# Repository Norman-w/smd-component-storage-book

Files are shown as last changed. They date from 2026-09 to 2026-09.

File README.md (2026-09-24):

# 0603 编带收纳活页页

当前版本是 ISO A5 纵向页面，外廓 `148 × 210 mm`，默认 18 条平行滑道。页面左侧带常见 A5 六孔圆孔列，标签卡槽底面保持完整，卡槽由底板上方增高的 T 形墙体形成。

当前源模型为 v22：标签纸仍为 `25 × 9 mm`，从右向左插入；底板不再挖浅槽，标签上下两侧与编带槽共用“下宽上窄”的 T 形卡口。入口压边的外侧边保持直线，只让朝标签内侧的边收斜，俯视轮廓为“个”字形而不是两边都收窄的 Y 形。编带内宽约 `8.6 mm`，双侧 T 形压边每侧覆盖约 `1.3 mm`，顶部有效开口约 `6.0 mm`；相邻滑道用约 `0.8 mm` 共用薄墙直接相接，页面保持 18 条滑道。

当前工作树保留连续外圈围墙：围墙高约 `3.45 mm`、平面内墙厚 `2.0 mm`，从页面最外缘向内形成加强边，既帮助装订后保持页面平整，也作为每条编带滑道的右端止挡。左侧装订区域从页面边缘到孔列内侧加强脊全部满铺到同一高度，孔洞贯穿高台，以提升装订孔抗撕裂能力。新版导出文件使用 `_v22_z_wall_t_slot` 文件名。

## 使用与商业授权

本作品默认仅供个人学习、测试、收藏和非商业打印使用。未经作者书面许可，禁止将原模型或任何基于本模型的改造、缩放、修补、重混或衍生版本用于商业用途，包括但不限于：销售打印件、按需打印或代打服务、批量生产、产品配套或赠品、手板/复模、定制服务、商业展示，以及上传或销售商业衍生模型。

如需商业使用，请在使用前联系作者（MakerWorld / GitHub：`@NormanWang`）取得书面授权，并另行约定授权费、单件费用、销售额分成或利润分成。未获授权的商业使用，作者保留要求停止使用、下架、追究侵权责任及索取相应授权费用或损害赔偿的权利。完整条款见 [`LICENSE.md`](LICENSE.md)。

## 设计假设

- FDM / PETG / 0.4 mm 喷嘴；底板为 `0.6 mm` 极薄版本，约对应 0.2 mm 层高的 3 层实体，不是单层空壳。
- T 形压边每侧内收 `1.3 mm`，压边材料厚 `1.0 mm`、上压高度 `0.9 mm`；相邻 `11.0 mm` 行距滑道共用约 `0.8 mm` 薄隔档，目标为普通 PETG、0.4 mm 喷嘴、无支撑打印。
- 页面平放打印，设计目标是不使用支撑。
- 页面最外圈增加连续圆角围墙，平面内墙厚 `2.0 mm`、高度与 T 形滑道最高点一致；编带滑道直接延伸到外墙内侧，不再额外设置右端挡块。
- 载带默认按 8 mm 压纹塑料带估算：宽度 8 mm、最大凸包高度 1.8 mm。
- 双侧 T 形限位是正式页面默认结构；单侧 7 形只用于对照测试片。
- 装订孔默认采用 A5 六孔制式，孔径 `5.5 mm`，孔中心距左边 `6.5 mm`，纵向位置为 `32 / 51 / 70 / 140 / 159 / 178 mm`；参数可在 `src/params.scad` 调整。
- 标签槽右边缘与对应滑道入口约留 `1 mm`，纸片标签从右向左插入，左端由装订孔旁加强高台止挡，标签槽挪出的空间让给编带滑道。
- 标签纸仍按 `25 × 9 mm` 使用；标签卡槽不削薄 `0.6 mm` 底板，支脚从底板顶面向上增高，标签下方有效容纳高度约 `0.7 mm`。主体上、下压边覆盖量约 `2.8 mm`，每格右侧入口前 `4.5 mm` 采用上下镜像的浅压边；外侧边保持直线，只收窄朝标签内侧的边。相邻标签共用水平隔档，主体标签窗口仍保留约 `9.8 mm` 高度。
- 滑道入口改为短装入豁口：横挡后的实际窗口约 `6 mm`，左端横挡高度降为 `1.8 mm`，T 形压边从其后立即开始，兼顾推进手感和防掉出。
- 编带槽内宽约 `8.6 mm`，顶部有效开口约 `6.0 mm`，优先加强编带防脱；槽间不留空白，直接共用约 `0.8 mm` 薄隔档，共容纳 18 条滑道。
- 所有载带包络和配合间隙集中在 `src/params.scad`。

## 导出

本机 OpenSCAD 应用程序路径：

```sh
OPENSCAD=/Applications/OpenSCAD.app/Contents/MacOS/OpenSCAD

"$OPENSCAD" --export-format binstl \
  -o output/3d-print/0603_tape_page_v22_z_wall_t_slot.stl \
  src/0603_tape_page.scad

"$OPENSCAD" --export-format binstl \
  -o output/3d-print/0603_fit_coupon_dual_t_v22_z_wall_t_slot.stl \
  -D 'model_selector="fit_dual_t"' src/0603_tape_page.scad

"$OPENSCAD" --export-format binstl \
  -D 'model_selector="fit_single_7"' \
  -o output/3d-print/0603_fit_coupon_single_7_v22_z_wall_t_slot.stl \
  src/0603_tape_page.scad
```

底板完整 + 标签上凸 T 形墙 + 单侧内边斜入口 + 装订边满铺加强版 v22 输出：

```text
output/3d-print/0603_tape_page_v22_z_wall_t_slot.stl
output/3d-print/0603_fit_coupon_dual_t_v22_z_wall_t_slot.stl
```

## 16 mm 编带变体

16 mm 版采用紧凑共墙布局，修正了旧版每格之间出现额外空白隔道的问题：

- 编带有效内宽 `16 mm`
- A5 页面 `11` 条滑道
- 行距 `17.2 mm = 16.0 + 0.2 + 0.8 + 0.2`
- `0.8 mm` 是相邻轨道共用的一条薄墙；不再在两条轨道之间额外插入第二条隔墙
- 两侧各保留 `0.2 mm` 装入余量
- 编带凸包高度仍按当前版本的 `1.8 mm`；若实物高度不同，只需调整 `tape_height`

导出 16 mm 整页和双侧 T 测试片：

```sh
"$OPENSCAD" --export-format binstl \
  -D 'tape_width=16' -D 'tape_side_clearance=0.2' \
  -D 'lane_count=11' -D 'lane_pitch=17.2' -D 'label_height=12' \
  -o output/3d-print/0603_tape_page_16mm_label12_tight_v1.stl \
  src/0603_tape_page.scad

"$OPENSCAD" --export-format binstl \
  -D 'model_selector="fit_dual_t"' \
  -D 'tape_width=16' -D 'tape_side_clearance=0.2' \
  -D 'lane_count=11' -D 'lane_pitch=17.2' -D 'label_height=12' \
  -o output/3d-print/0603_fit_coupon_dual_t_16mm_label12_tight_v1.stl \
  src/0603_tape_page.scad

"$OPENSCAD" --export-format binstl \
  -D 'model_selector="fit_single_7"' \
  -D 'tape_width=16' -D 'tape_side_clearance=0.2' \
  -D 'lane_count=11' -D 'lane_pitch=17.2' -D 'label_height=12' \
  -o output/3d-print/0603_fit_coupon_single_7_16mm_label12_tight_v1.stl \
  src/0603_tape_page.scad
```

对应的紧凑 16 mm STL 位于 `output/3d-print/`，整页包围盒为 `148 × 210 × 3.45 mm`，并通过封闭流形检查。

### 16 mm 编带 + 12 mm 标签变体

针对 16 mm 编带，平台发布版使用标签横向宽度 `12 mm`；标签沿插入方向的长度仍为 `25 mm`。这只覆盖 `label_height=12`，并使用紧凑的 `17.2 mm` 行距。

```sh
"$OPENSCAD" --export-format binstl \
  -D 'tape_width=16' -D 'tape_side_clearance=0.2' \
  -D 'lane_count=11' -D 'lane_pitch=17.2' \
  -D 'label_height=12' \
  -o output/3d-print/0603_tape_page_16mm_label12_tight_v1.stl \
  src/0603_tape_page.scad

"$OPENSCAD" --export-format binstl \
  -D 'model_selector="fit_dual_t"' \
  -D 'tape_width=16' -D 'tape_side_clearance=0.2' \
  -D 'lane_count=11' -D 'lane_pitch=17.2' \
  -D 'label_height=12' \
  -o output/3d-print/0603_fit_coupon_dual_t_16mm_label12_tight_v1.stl \
  src/0603_tape_page.scad
```

整页 12 mm 标签变体同样为 `148 × 210 × 3.45 mm`，并已通过封闭流形检查。

## 平台发布的六种编带宽度

平台草稿准备提供六份独立的整页 STL，避免用户误选宽度：

| 编带有效内宽 | 标签卡 | 滑道数 / 行距 | 平台文件 |
|---:|---:|---:|---|
| 8 mm | 25 × 9 mm | 18 / 11.0 mm | `output/3d-print/0603_tape_page_8mm_label9_v1.stl` |
| 12 mm | 25 × 12 mm | 15 / 13.2 mm | `output/3d-print/0603_tape_page_12mm_label12_v1.stl` |
| 16 mm | 25 × 12 mm | 11 / 17.2 mm | `output/3d-print/0603_tape_page_16mm_label12_tight_v1.stl` |
| 24 mm | 25 × 12 mm | 8 / 25.2 mm | `output/3d-print/0603_tape_page_24mm_label12_v1.stl` |
| 32 mm | 25 × 12 mm | 6 / 33.2 mm | `output/3d-print/0603_tape_page_32mm_label12_v1.stl` |
| 44 mm | 25 × 12 mm | 4 / 45.2 mm | `output/3d-print/0603_tape_page_44mm_label12_v1.stl` |

8 mm 和 12 mm 沿用已经确认/打印验证的页面；16 / 24 / 32 / 44 mm 使用紧凑共墙布局。六种版本都是 A5、六孔、完整底板、连续外圈围墙和双侧 T 形编带限位。

24 / 32 mm 版本暂按 `3.0 mm` 载带/料槽高度包络建模；44 mm 版本暂按 `3.6 mm` 高度包络建模，作为 ESP32-WROOM 类模组载带的初始版本。载带宽度、料槽深度和元件凸包高度仍需以实物测量为准，正式装满整卷前应先打印对应测试片。

## B5 横向长轨变体

为在左侧继续装订/开合的前提下增加左右方向的存储长度，另提供 `250 × 176 mm` 的 ISO B5 横向页面。左侧保留六孔，孔径 `5.5 mm`，孔距 `19 mm`，孔中心位置为 `15 / 34 / 53 / 123 / 142 / 161 mm`。250 mm 长边在 X1C 的 256 mm 打印轴内约剩 3 mm 单边余量，打印时应精确放置并关闭 brim。

| 编带有效内宽 | 滑道数 / 行距 | 页面高度 | 平台文件 |
|---:|---:|---:|---|
| 8 mm | 15 / 11.0 mm | 3.45 mm | `output/3d-print/0603_tape_page_b5_8mm_label9_v1.stl` |
| 12 mm | 12 / 13.2 mm | 3.45 mm | `output/3d-print/0603_tape_page_b5_12mm_label12_v1.stl` |
| 16 mm | 9 / 17.2 mm | 3.45 mm | `output/3d-print/0603_tape_page_b5_16mm_label12_tight_v1.stl` |
| 24 mm | 6 / 25.2 mm | 4.65 mm | `output/3d-print/0603_tape_page_b5_24mm_label12_v1.stl` |
| 32 mm | 5 / 33.2 mm | 4.65 mm | `output/3d-print/0603_tape_page_b5_32mm_label12_v1.stl` |
| 44 mm | 3 / 45.2 mm | 5.25 mm | `output/3d-print/0603_tape_page_b5_44mm_label12_v1.stl` |

B5 版的编带插入方向有效长度约 `208 mm`，约为当前 A5 版 `106 mm` 的两倍；相邻滑道仍直接共用约 `0.8 mm` 薄隔墙。

## 当前打印验证版：12 mm 编带 + 12 mm 标签

本次打印采用独立的 A5 版本：编带净宽按 `12 mm`，标签卡按 `25 × 12 mm`，页面共 `15` 条滑道，滑道中心距为 `13.2 mm`。中心距按 `12 mm` 有效空间、约 `0.8 mm` 共用隔墙和两侧合计 `0.4 mm` 装入余量计算；相邻滑道直接共墙，不再留无效空隙。

该版本仍保留 A5 六孔装订、完整 `0.6 mm` 底板、上凸 T 形卡槽、连续 `2.0 mm` 外圈加强墙和无支撑平放打印目标。整页包围盒为 `148 × 210 × 3.45 mm`，页面与双 T 测试片均通过封闭流形检查。X1C 直接打印工程使用普通 PETG、纹理 PEI 板和 `0.20 mm` 层高。

对应文件：

```text
output/3d-print/0603_tape_page_12mm_label12_v1.stl
output/3d-print/0603_tape_page_12mm_label12_x1c_safe_v1.stl
output/3d-print/0603_tape_page_12mm_label12_x1c_petg_v1.3mf
output/3d-print/0603_fit_coupon_dual_t_12mm_label12_v1.stl
```

`_x1c_safe_v1.stl` 已将页面放到 X1C 床面安全区域；`.3mf` 是已切片的直接打印工程。当前版本先保留为独立输出，不改变 `src/params.scad` 中默认的 8 mm 编带参数。

### X1C 直接打印工程

为避免 Bambu Studio 导入 STL 后把页面放进左下角校准避让区，另提供同一几何体的 X1C 安全坐标包装版：页面位于 `x=54..202 mm`、`y=23..233 mm`，几何包围盒仍为 `148 × 210 × 3.45 mm`。

```text
src/0603_tape_page_16mm_label12_tight_x1c_safe.scad
output/3d-print/0603_tape_page_16mm_label12_tight_v1.stl
```

16 mm 紧凑版目前先提供已验证的 STL 和 X1C 安全坐标包装源文件；三种宽度的统一 3MF 工程待平台版本确认后再生成。打印时使用 Bambu Lab X1 Carbon、0.4 mm 喷嘴、0.20 mm Standard、普通 PETG、纹理 PEI 板；发送到打印机时可在 AMS 中把普通 PETG 映射到第 3 或第 4 槽。

## 打印前检查

先打印测试片，用实际 0603 编带验证插入、竖直防脱、镊子取料和 `25 × 9 mm` 标签插入。确认后再打印整页。PETG 大面积平板建议使用干燥耗材、纹理 PEI，并按切片结果决定是否加小幅 brim。

STL 导出后还需要检查包围盒、流形性、底面连续性和 T 形压边是否能无支撑成形。STL 导出成功本身不等于实际配合已经验证。

## X1C 局域网打印工程

已准备好可直接在 Bambu Studio 打开的切片工程：

```text
output/3d-print/0603_tape_page_v1_x1c_petg_standard.3mf
```

工程使用 Bambu Lab X1 Carbon、0.4 mm 喷嘴、PETG Basic 和纹理 PEI 板，并在工程内明确写入 `256 × 256 × 256 mm` 打印区及左下角 `18 × 28 mm` 校准避让区。当前 v4 页面通过 `src/0603_tape_page_x1c_safe.scad` 以 `54 / 23 mm` 放置，实际页面约为 `148 × 210 × 3.45 mm`，不会占用左下校准区。

质量优先参数：

- 层高 `0.20 mm`，首层 `0.20 mm`；2 圈外墙，底部 3 层，顶部 4 层，填充 `0%`。
- PETG 喷嘴 `255°C`，纹理 PEI 热床首层及其余层 `80°C`。
- 首层 `20 mm/s`，外墙 `45 mm/s`，内墙 `60 mm/s`，顶面 `60 mm/s`。
- 默认/外墙加速度 `500 mm/s²`，首层 `300 mm/s²`，风扇范围 `10–40%`，最大体积流量 `8 mm³/s`。
- 关闭 skirt，外裙边改为 `1 mm`；A5 页面在 X1C 床面上有充足边缘余量，可按首层观察结果决定是否加 brim。

该 `.3mf` 是上一版 B5 工程，不能代表当前 A5 v22 几何；正式打印前应在 Bambu Studio 中导入新的 v22 STL，确认 X1C 当前装的是干燥 PETG、纹理 PEI 板已清洁，并先用双 T 测试片确认实际编带和右侧标签配合。

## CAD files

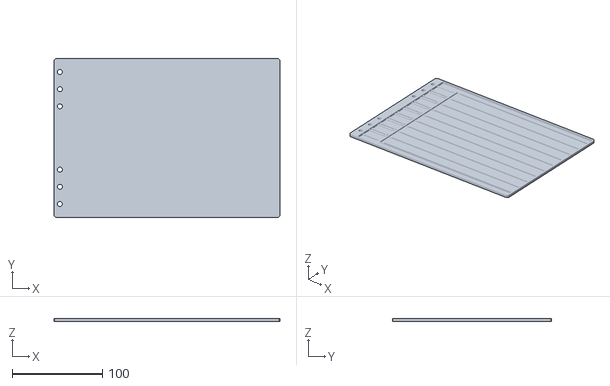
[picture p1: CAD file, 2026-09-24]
output/3d-print/0603_tape_page_b5_16mm_label12_tight_v1.stl
250.0 x 176.0 x 3.45

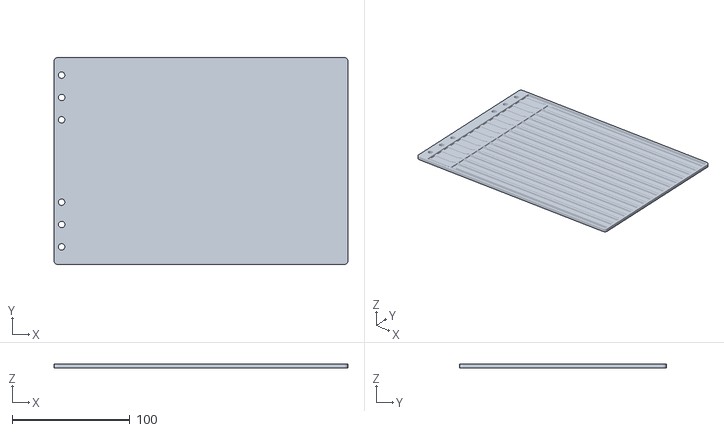
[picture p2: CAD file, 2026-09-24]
output/3d-print/0603_tape_page_b5_8mm_label9_v1.stl
250.0 x 176.0 x 3.45

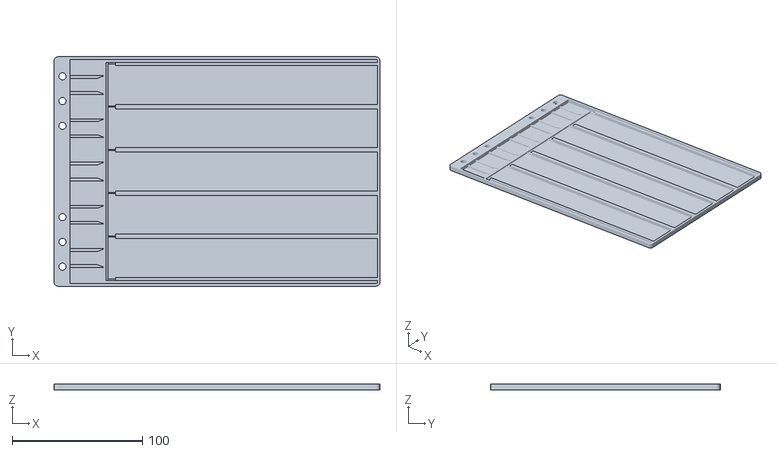
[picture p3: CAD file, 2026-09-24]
output/3d-print/0603_tape_page_b5_32mm_label12_v1.stl
250.0 x 176.0 x 4.65

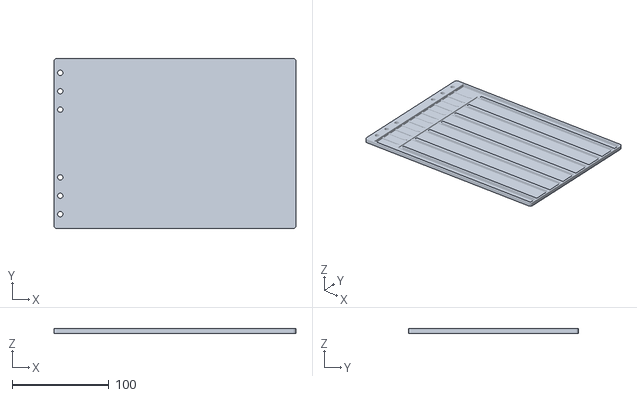
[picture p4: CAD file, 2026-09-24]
output/3d-print/0603_tape_page_b5_24mm_label12_v1.stl
250.0 x 176.0 x 4.65

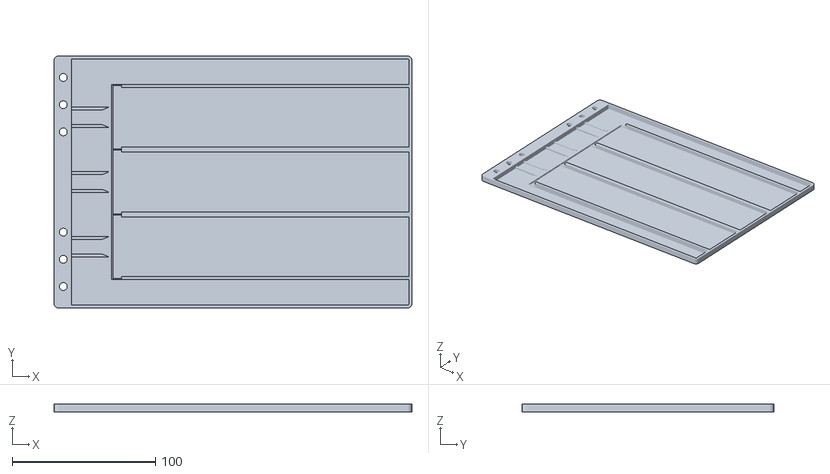
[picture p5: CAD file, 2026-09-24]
output/3d-print/0603_tape_page_b5_44mm_label12_v1.stl
250.0 x 176.0 x 5.25

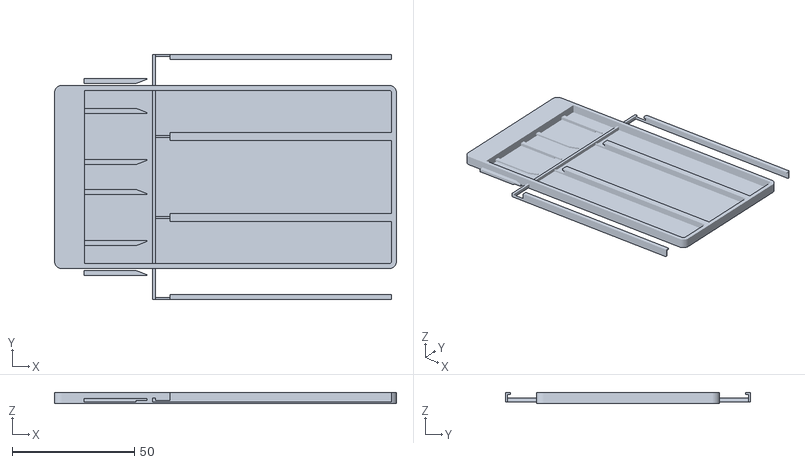
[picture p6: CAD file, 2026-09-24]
output/3d-print/0603_fit_coupon_dual_t_32mm_label12_v1.stl
140.0 x 100.4 x 4.65

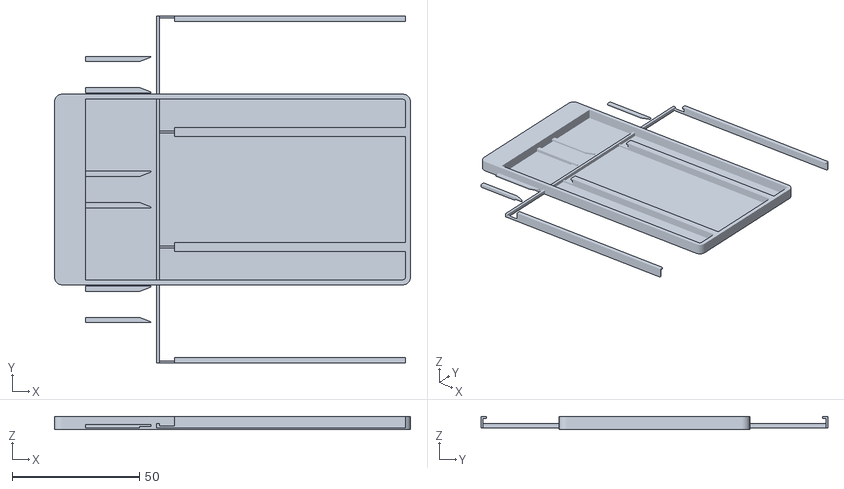
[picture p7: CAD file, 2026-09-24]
output/3d-print/0603_fit_coupon_dual_t_44mm_label12_v1.stl
140.0 x 136.4 x 5.25

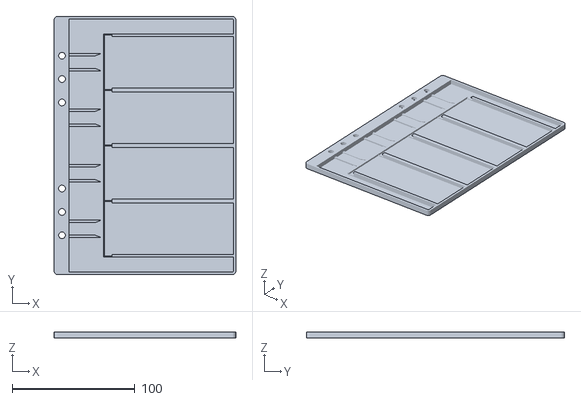
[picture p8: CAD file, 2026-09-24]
output/3d-print/0603_tape_page_44mm_label12_v1.stl
148.0 x 210.0 x 5.25

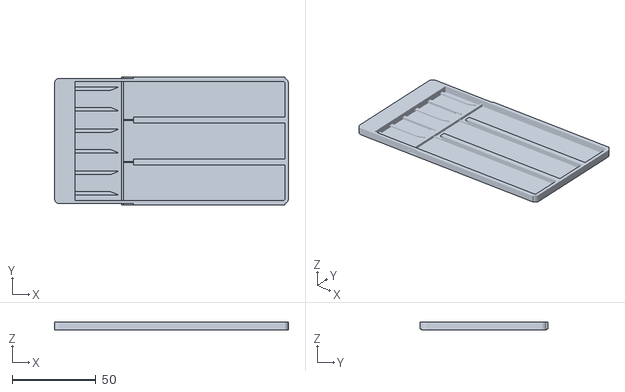
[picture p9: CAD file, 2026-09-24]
output/3d-print/0603_fit_coupon_dual_t_24mm_label12_v1.stl
140.0 x 76.4 x 4.65

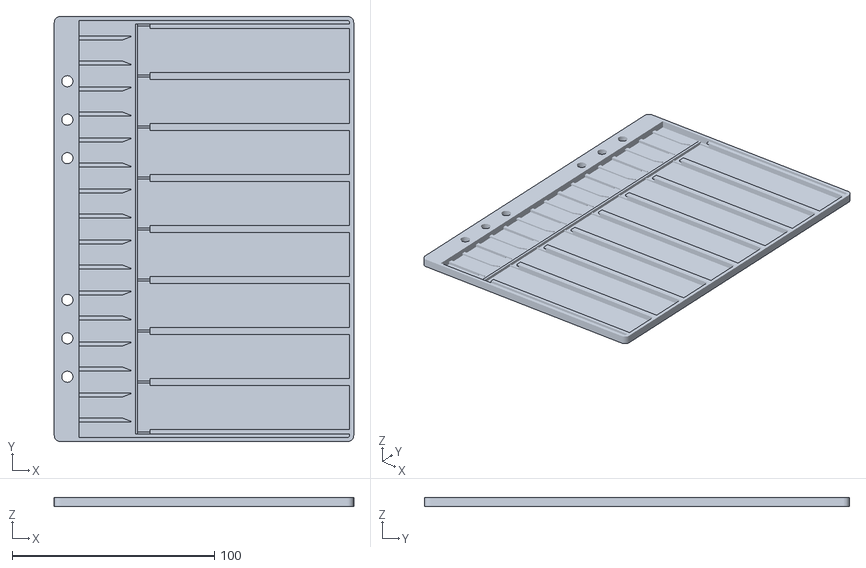
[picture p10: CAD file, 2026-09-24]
output/3d-print/0603_tape_page_24mm_label12_v1.stl
148.0 x 210.0 x 4.65

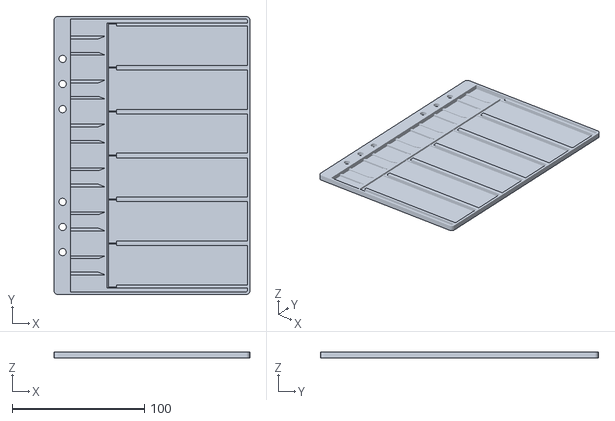
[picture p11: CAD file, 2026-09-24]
output/3d-print/0603_tape_page_32mm_label12_v1.stl
148.0 x 210.0 x 4.65

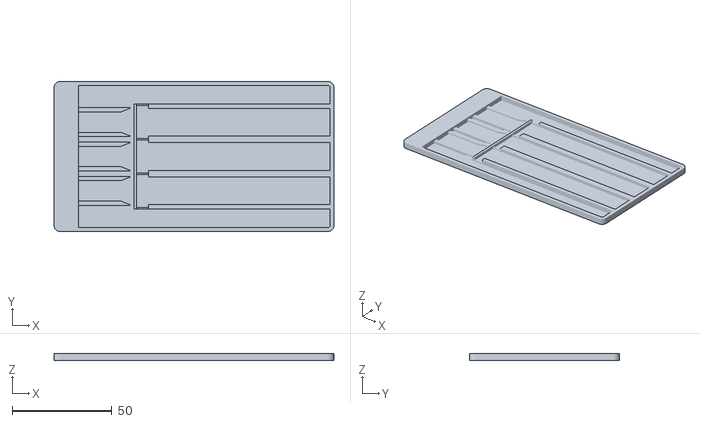
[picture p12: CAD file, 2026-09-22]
output/3d-print/0603_fit_coupon_dual_t_16mm_label12_tight_v1.stl
140.0 x 75.0 x 3.45

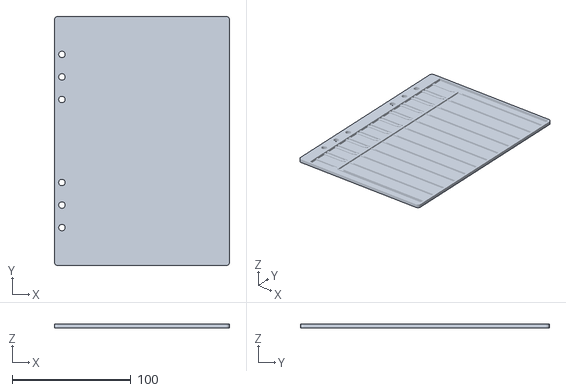
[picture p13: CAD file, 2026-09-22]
output/3d-print/0603_tape_page_16mm_label12_tight_v1.stl
148.0 x 210.0 x 3.45

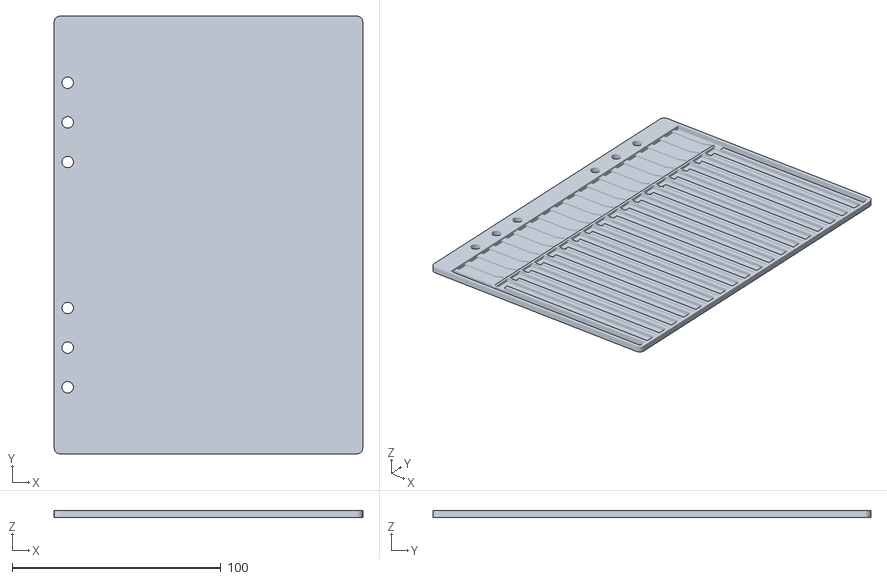
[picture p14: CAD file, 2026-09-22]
output/3d-print/0603_tape_page_8mm_label9_v1.stl
148.0 x 210.0 x 3.45

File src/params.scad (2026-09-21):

// 0603 编带收纳页 v22 参数
// 单位：mm；默认按 A5 纵向页面、PETG、0.4 mm 喷嘴、平放无支撑打印。

// 页面：ISO A5 纵向比例；比 B5 更紧凑，适合常见活页夹系统。
page_width = 148;
page_height = 210;
// 极薄底板：按 0.2 mm 层高约 3 层设计；优先减薄，必须先做翘曲实测。
base_thickness = 0.6;
corner_radius = 3;

// A5 常见 6 孔活页制式；内容区从孔列右侧开始。
// 19 / 19 / 70 / 19 / 19 mm 分组孔距，约 5.5 mm 圆孔。
binding_holes_enabled = true;
binding_hole_count = 6;
binding_hole_pitch = 19;
binding_hole_diameter = 5.5;
binding_hole_center_x = 6.5;
binding_margin = 16;
binding_hole_pattern_enabled = true;
binding_hole_positions = [32, 51, 70, 140, 159, 178];
// 活页孔列内侧的加强脊：不遮挡孔，和上下围墙连接以提高装订边刚度。
binding_spine_wall_enabled = true;
binding_spine_wall_width = 2.0;
binding_spine_wall_x = binding_hole_center_x + binding_hole_diameter / 2 + 1.0;
// 装订边从页面左缘到这条加强脊全部抬高铺满；孔位随后贯穿整段高台。
// 这既提高孔边抗撕裂能力，也让加强脊可以直接作为标签槽左端止档。
binding_full_fill_enabled = true;
binding_full_fill_until_x = binding_spine_wall_x + binding_spine_wall_width;

// 标签与滑道布局
// 25×9 mm 标签仍保留足够开口；利用相邻标签共享的水平隔档压缩行距。
lane_count = 18;
lane_pitch = 11.0;
label_width = 25;
label_height = 9;
label_clearance = 0.4;
// 标签槽不再从底板顶面向下挖；标签直接落在完整底板上，
// 通过向上增加 T 形导轨墙体来形成卡槽。
label_recess_depth = 0.0;
// 标签槽直接沿用编带槽的截面参数：窄支脚 0.8 mm，顶部横梁
// 向槽内压入 1.3 mm。标签底部通道仍按 9.8 mm 留量设计。
label_frame_thickness = 0.8;
label_lip_inset = 0;
// 标签 T 导轨与编带导轨使用同一压边厚度；标签下方有效容纳高度
// 单独放宽到 0.7 mm，可容纳较厚纸卡、覆膜卡或多层标签。
label_stem_width = 0.8;
label_cap_overlap = 1.3;
label_cap_thickness = 0.8;
label_card_clear_height = 0.7;
label_lip_height = label_card_clear_height + label_cap_thickness;
// 标签从右侧插入时，入口前 4.5 mm 采用上下镜像的浅压边，
// 形成真正的“八字口”：右侧开口更宽，向左过渡到完整凸压边。
// 这里的深度是沿页面横向的压边厚度。
label_entry_relief_length = 4.5;
label_entry_frame_depth = 1.4;
// XY 俯视轮廓的单尖点保留 0.35 mm 平口，避免零厚度尖端和非流形面；
// 这只是标签入口轮廓，编带滑道的 YZ 截面 T 形不受影响。
label_entry_point_depth = 0.35;
// 标签入口只收窄靠标签内侧的压边，外侧边线保持直线；
// 这样相邻墙顶形成“个”字形，而不是两侧都收窄的“Y”字形。
label_entry_inner_edge_only = true;
// 每个标签格的入口上下镜像形成八字口：两侧都是连续的凸压边，
// 右端浅、左端深；不再用相邻行交错或凹进去的阶梯表达入口。
// 标签入口不再使用中央竖向止退斜台，防止俯视图出现多余挡条；
// 标签由上下 T 形压边自身卡住。
// 标签槽结束后保留 2 mm 的结构间隙，标签直接从隔墙侧进入。
// 标签槽镜像到右侧开口，从右向左插入；左端止档使用装订边加强脊。
label_column_width = label_width + 2 * label_clearance;
track_gap_after_label = 2.0;
right_edge_margin = 3;

// 8 mm 压纹塑料载带的初始包络；拿到实物后只需调整这些参数。
tape_width = 8;
tape_height = 1.8;
tape_side_clearance = 0.3;
top_clearance = 0.25;

// 限位结构
// 轨道支脚与相邻轨道之间的共用隔档最薄处均控制在约 0.8 mm。
// 这是针对 0.4 mm 喷嘴 PETG 的紧凑上限；若实测强度不足，退回 1.0 mm。
rail_stem_width = 0.8;
lane_partition_enabled = true;
lane_partition_top_width = 0.8;
lane_partition_overlap = 0.02;
// 每侧向内压住编带 1.3 mm；顶部有效开口约为 6.0 mm。
rail_cap_overlap = 1.3;
rail_cap_thickness = 0.8;
// 页面最外圈连续围墙：从纸张边缘向内占 2 mm；高度与当前 T 形滑道最高点一致。
perimeter_wall_enabled = true;
perimeter_wall_width = 2.0;
perimeter_wall_inset = 0.0;
perimeter_wall_height = base_thickness + tape_height + top_clearance + rail_cap_thickness;
entry_stop_thickness = 1.2;
// 横挡后保留 6 mm 装入/取料窗口；T 形压边从其后立即开始。
entry_notch_length = 6.0;
entry_zone_length = entry_stop_thickness + entry_notch_length;
// 左端挡板不再高出载带包络，便于将带头压入窗口后向右推。
entry_stop_height = 1.8;
end_stop_thickness = 2.0;
entry_guide_height = 0.8;
single_hook_guide_height = 0.9;

// 运行根文件时的默认模型；测试片通过独立 wrapper 调用。
model_selector = "page";
rail_profile = "dual_t";

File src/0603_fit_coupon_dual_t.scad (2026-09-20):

// 双侧 T 形限位测试片
use <0603_tape_page.scad>;

fit_coupon("dual_t");

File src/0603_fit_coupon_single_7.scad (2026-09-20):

// 单侧 7 形限位测试片
use <0603_tape_page.scad>;

fit_coupon("single_7");

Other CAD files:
output/3d-print/0603_tape_page_b5_12mm_label12_v1.stl
output/3d-print/0603_tape_page_12mm_label12_x1c_petg_v1.3mf
output/3d-print/0603_tape_page_12mm_label12_v1.stl
output/3d-print/0603_fit_coupon_dual_t_12mm_label12_v1.stl
src/0603_tape_page.scad
output/3d-print/0603_fit_coupon_dual_t.stl
output/3d-print/0603_fit_coupon_dual_t_16mm_label12_v1.stl
output/3d-print/0603_fit_coupon_dual_t_v2.stl
output/3d-print/0603_fit_coupon_dual_t_v22_z_wall_t_slot.stl
output/3d-print/0603_fit_coupon_dual_t_v3.stl
output/3d-print/0603_fit_coupon_dual_t_v3_perimeter.stl
output/3d-print/0603_fit_coupon_dual_t_v4_right_label.stl
output/3d-print/0603_fit_coupon_dual_t_v5_thin_partition.stl
output/3d-print/0603_fit_coupon_dual_t_v6_08mm_partition.stl
output/3d-print/0603_fit_coupon_dual_t_v7_label_entry_relief.stl
output/3d-print/0603_fit_coupon_dual_t_v8_alternating_label_mouth.stl
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

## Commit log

2026-09-20 Initial 0603 tape storage page
    [0603_fit_coupon_dual_t.scad, 0603_fit_coupon_dual_t.stl, 0603_fit_coupon_single_7.scad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]
2026-09-20 Use standard PETG print profile for MakerWorld
    [0603_tape_page_v1_x1c_petg_standard.3mf]
2026-09-20 Improve label retention lip for v2
    [0603_fit_coupon_dual_t_v2.stl, 0603_fit_coupon_single_7_v2.stl, 0603_tape_page.scad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]
2026-09-20 Tighten 0603 tape lanes and move page to A5 v3
    [0603_fit_coupon_dual_t_v3.stl, 0603_fit_coupon_single_7_v3.stl, 0603_tape_page.scad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]
2026-09-20 Add reinforced perimeter and commercial use terms
    [0603_fit_coupon_dual_t_v3_perimeter.stl, 0603_fit_coupon_single_7_v3_perimeter.stl, 0603_tape_page.scad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]
2026-09-20 Mirror label slot and reinforce binder edge
    [0603_fit_coupon_dual_t_v4_right_label.stl, 0603_fit_coupon_single_7_v4_right_label.stl, 0603_tape_page.scad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]
2026-09-20 Thin lane partitions and reinforce label slots
    [0603_fit_coupon_dual_t_v5_thin_partition.stl, 0603_fit_coupon_single_7_v5_thin_partition.stl, 0603_tape_page.scad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]
2026-09-20 Add 18-lane 0.8mm partition variant
    [0603_fit_coupon_dual_t_v6_08mm_partition.stl, 0603_fit_coupon_single_7_v6_08mm_partition.stl, 0603_tape_page.scad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]
2026-09-20 Widen label entry mouth
    [0603_fit_coupon_dual_t_v7_label_entry_relief.stl, 0603_fit_coupon_single_7_v7_label_entry_relief.stl, 0603_tape_page.scad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]
2026-09-20 Alternate label entry mouths
    [0603_fit_coupon_dual_t_v8_alternating_label_mouth.stl, 0603_fit_coupon_single_7_v8_alternating_label_mouth.stl, 0603_tape_page.scad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]
2026-09-20 Make label entry mouths convex
    [0603_fit_coupon_dual_t_v9_convex_label_mouth.stl, 0603_fit_coupon_single_7_v9_convex_label_mouth.stl, 0603_tape_page.scad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]
2026-09-21 feat: add v22 raised-wall label slot
    [0603_fit_coupon_dual_t_v22_z_wall_t_slot.stl, 0603_tape_page.scad, 0603_tape_page_v22_z_wall_t_slot.stl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]
2026-09-22 feat: add 16mm page with 12mm labels
    [0603_fit_coupon_dual_t_16mm_label12_v1.stl, 0603_fit_coupon_single_7_16mm_label12_v1.stl, 0603_tape_page_16mm_label12_v1.stl]
2026-09-22 chore: add X1C print package for 16mm page
    [0603_tape_page_16mm_label12_x1c_petg_v1.3mf, 0603_tape_page_16mm_label12_x1c_safe.scad, 0603_tape_page_16mm_label12_x1c_safe_v1.stl]
2026-09-22 feat: add 12mm tape page print package
    [0603_fit_coupon_dual_t_12mm_label12_v1.stl, 0603_tape_page_12mm_label12_v1.stl, 0603_tape_page_12mm_label12_x1c_petg_v1.3mf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]
2026-09-22 feat: add compact 8 12 16mm release variants
    [0603_fit_coupon_dual_t_16mm_label12_tight_v1.stl, 0603_tape_page_16mm_label12_tight_v1.stl, 0603_tape_page_16mm_label12_tight_x1c_safe.scad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]
2026-09-24 📦 新增 24/32/44 mm 编带收纳版本
    [0603_fit_coupon_dual_t_24mm_label12_v1.stl, 0603_fit_coupon_dual_t_32mm_label12_v1.stl, 0603_fit_coupon_dual_t_44mm_label12_v1.stl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]
2026-09-24 📐 新增 B5 横向长轨版本
    [0603_tape_page_b5_12mm_label12_v1.stl, 0603_tape_page_b5_16mm_label12_tight_v1.stl, 0603_tape_page_b5_24mm_label12_v1.stl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]
